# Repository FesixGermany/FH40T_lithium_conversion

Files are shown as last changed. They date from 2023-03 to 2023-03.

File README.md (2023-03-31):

# FH40T conversion to lithium battery  

The FH40T is a quite popular antique geiger counter in Germany from company Frieseke and Hoepfner.  
This particular unit is marked with the year of manufacture 1963.  
Originally it was powered by a long forgotten 6V battery or a NiCd rechargable battery.  
The previous owner built a small adapter to use two CR-V3 lithium batteries in series.  
I figured it could be powered by a modern standard 18650 rechargable lithium batery.  

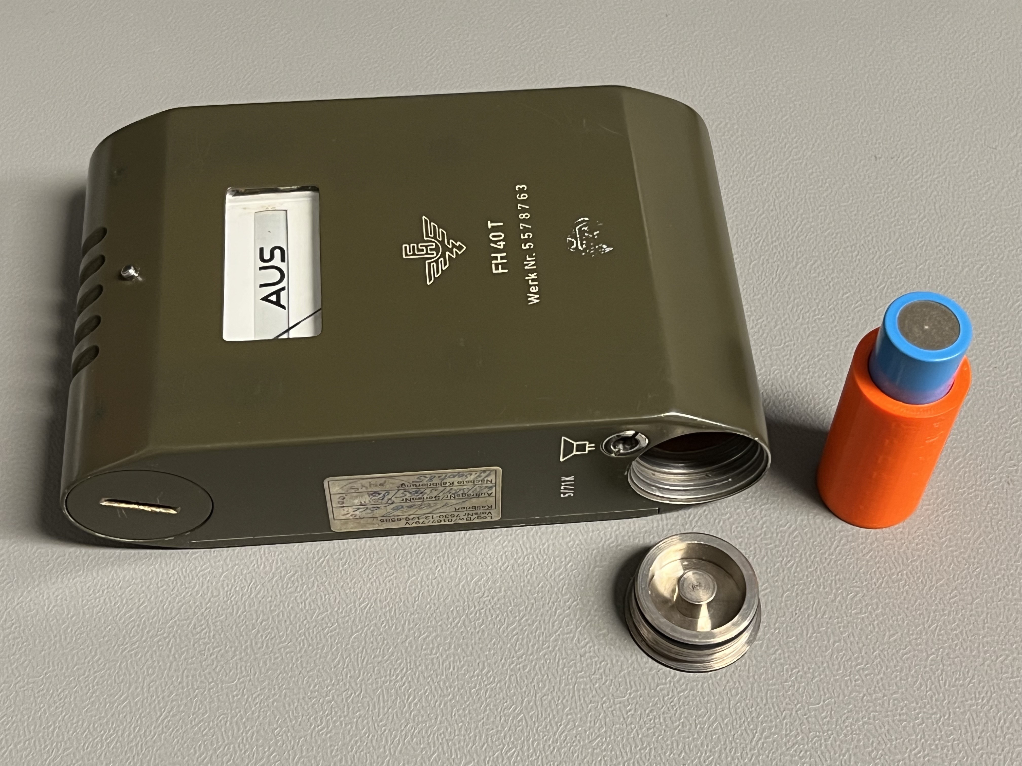
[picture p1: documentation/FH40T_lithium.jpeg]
FH40T with 18650 cell
  
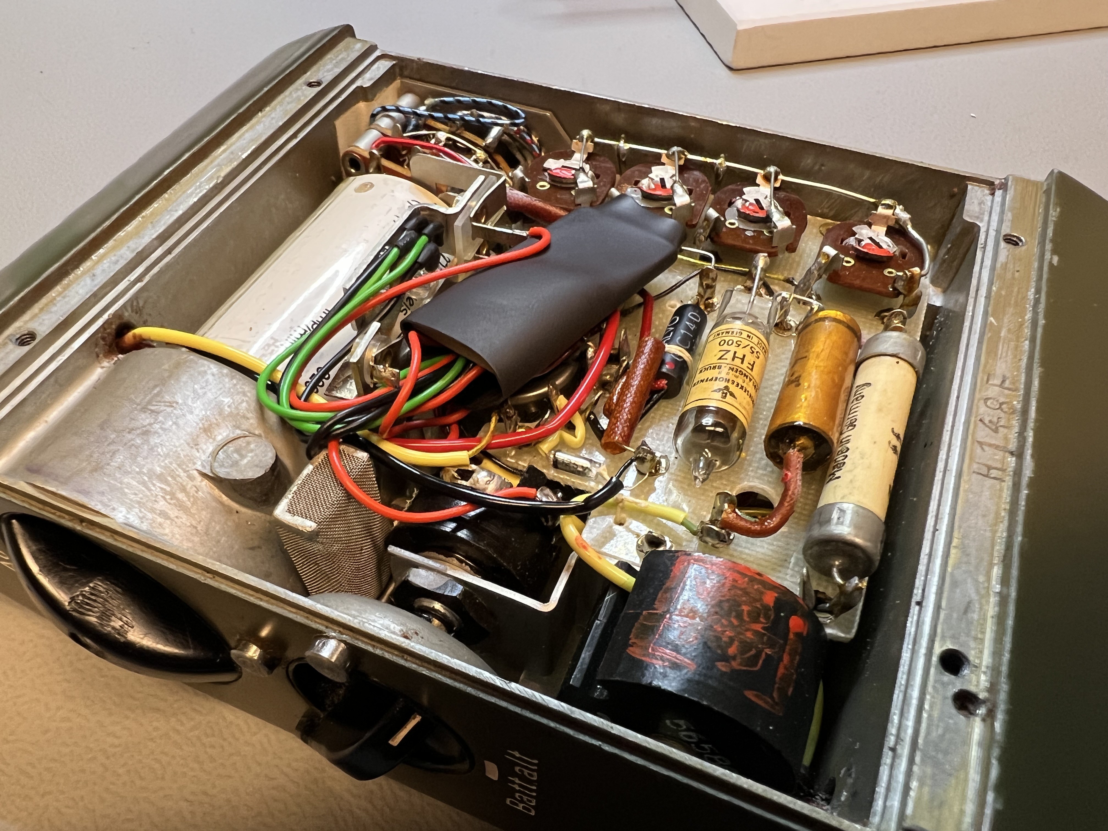
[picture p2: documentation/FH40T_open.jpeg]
FH40T with pcb
  

Needed was a adapter sleeve to fit the 18650 in the battery compartment, a protection circuit for the lithium cell and a step up converter to get a constant voltage.  
In addition I wanted to have some sort of carge indicator.  

## Protection circuit  

The protection circuit only needs to protect the cell against over discharging and is built around the standard DW01A protection IC.  
The only problem is, that normally it switches the low side of the connection. This can not be done with the FH40T because the whole case is used as ground.  
Therefore the P-channel MOSFET Q1 is used with help of Q2 to switch off the high side when the cell reaches 2.5V. R1 keeps the gate of Q1 discharged.  

## Step up converter  

The step up converter is built using the ME2108A IC I desoldered from a tiny step up module together with the schottky diode and inductor to provide a stable-ish voltage between 4.3V and 7V.  

## Charge indicator  

The charge indicator uses an ATtiny85 microcontroller that measures the voltage of the cell through a voltage divider consisting of R7 and R8, C4 was added in parallel to R8 for some low pass filtering.  
Although the controller is powered by the 5V from the step up it needs to use the internal 2.56V reference as the 5V is not stable enough.  
The cell voltage is displayed after the device is switched on by flashing a super bright red LED behind the scale and every time the voltage dropped by 100mV. Once the voltage dropped below 3V the LED flashes every 4s.  

## Lighting the scale  

Originally the scale was lit by a little incendescant bulb. Now a bright white LED is used switched on via Q3.  

## The PCB  

The PCB is a simple single sided board manufactures by isolation milling with my ISEL PCB router.  

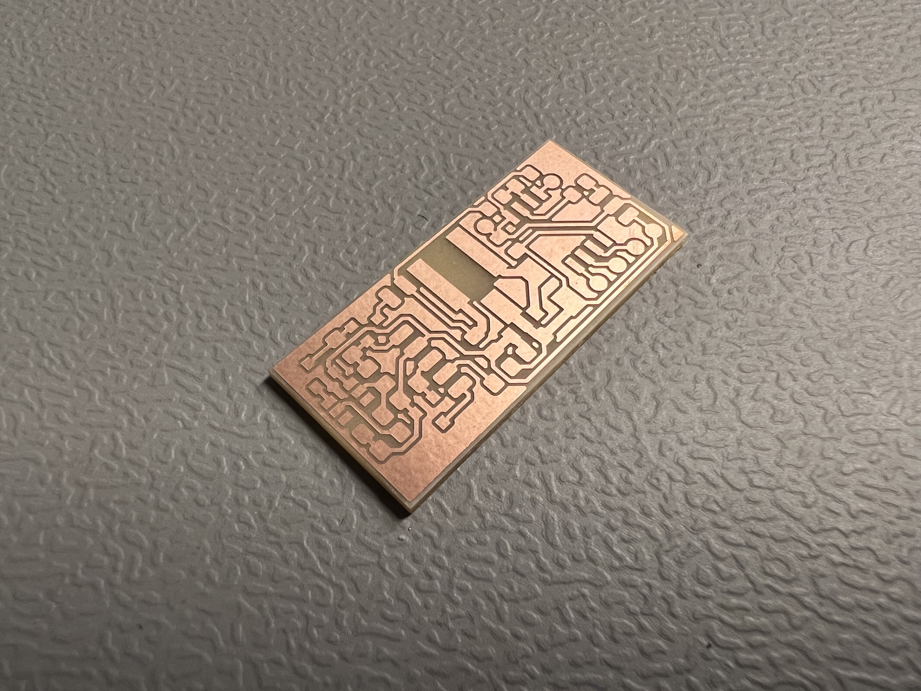
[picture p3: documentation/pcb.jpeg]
empty pcb
  
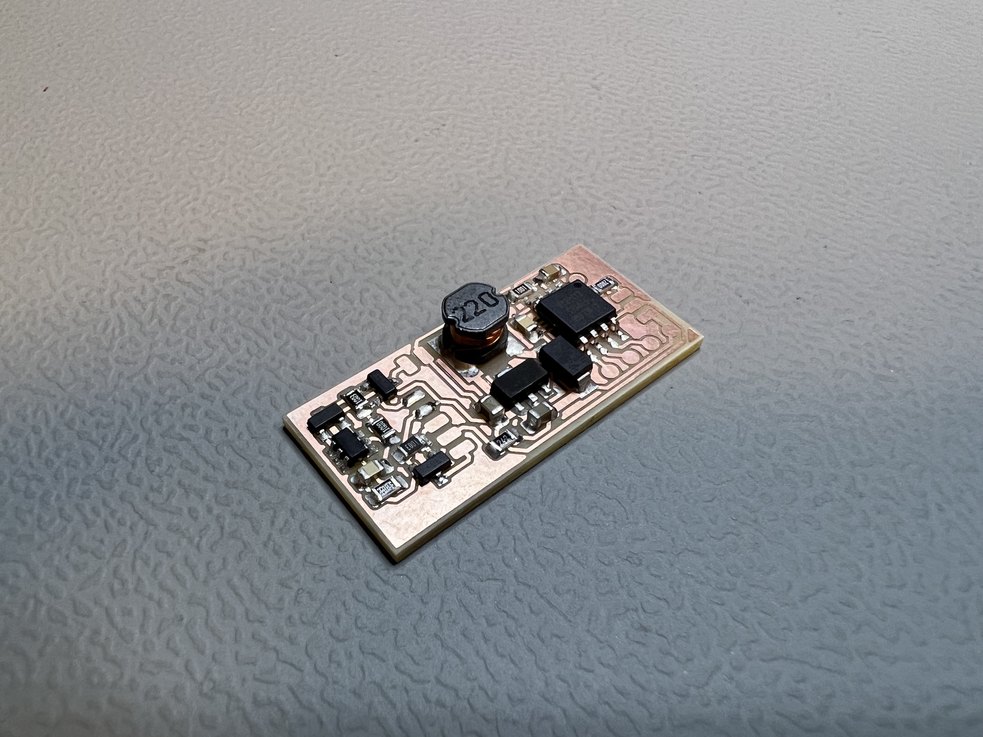
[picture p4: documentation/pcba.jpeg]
finished pcba
  

For interest here is the original schematic:  

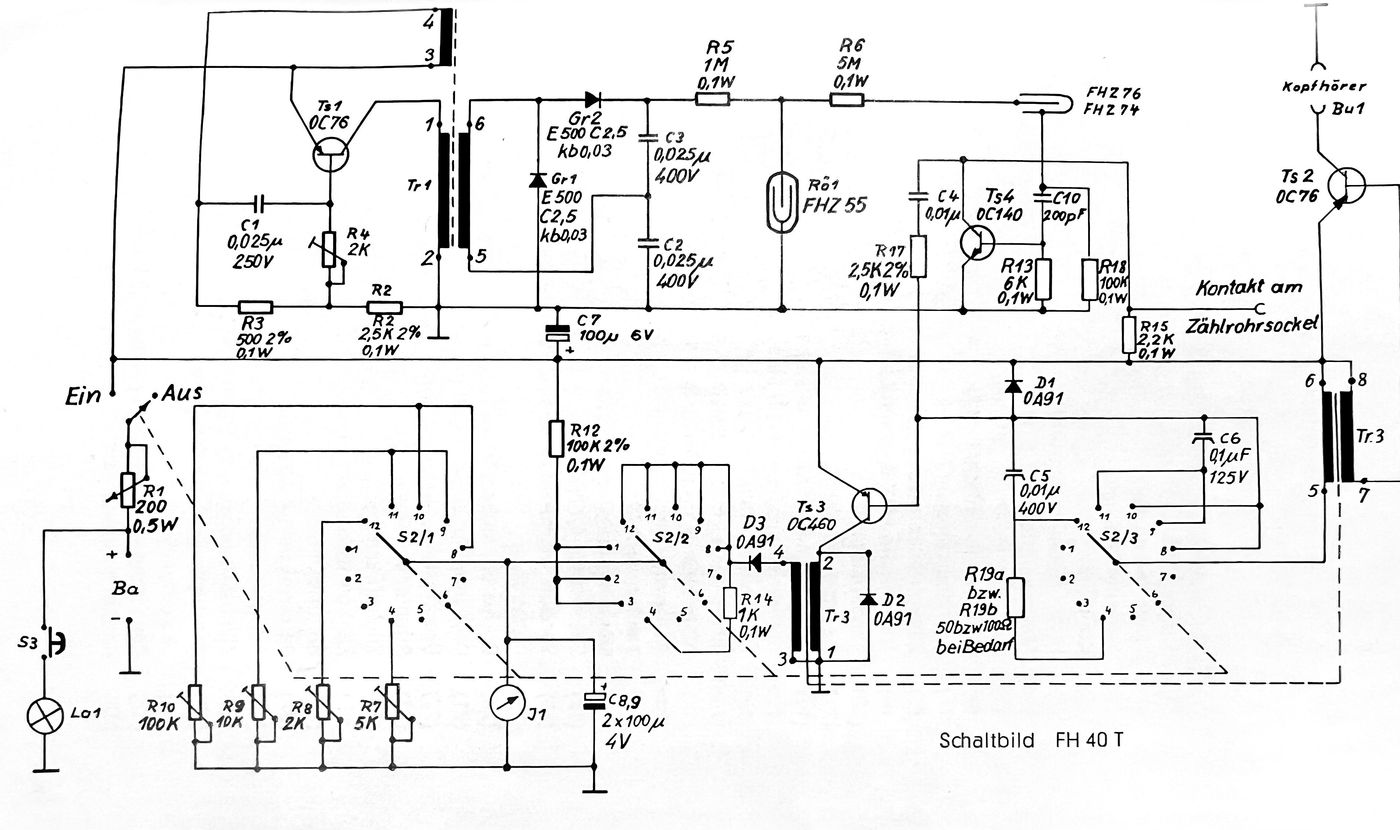
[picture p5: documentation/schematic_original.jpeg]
Original schematic


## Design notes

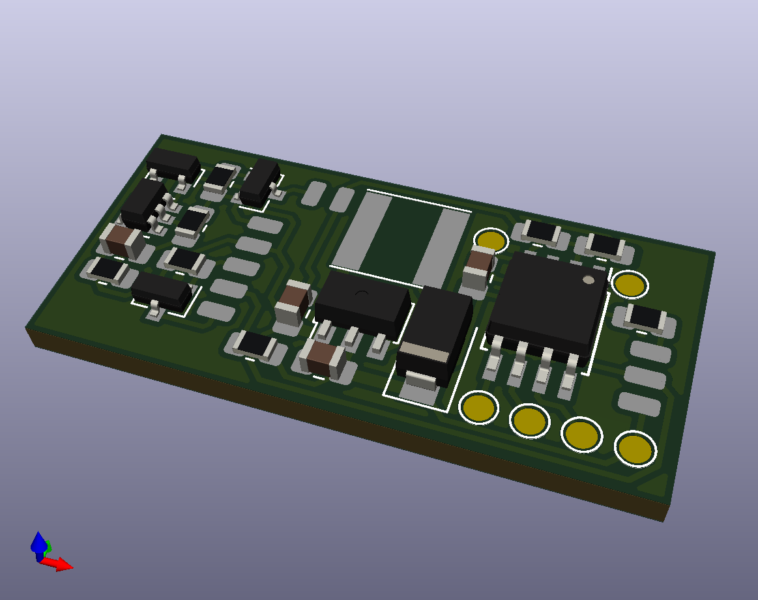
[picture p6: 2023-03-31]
pcb/FH40T_lithium_pcb.png

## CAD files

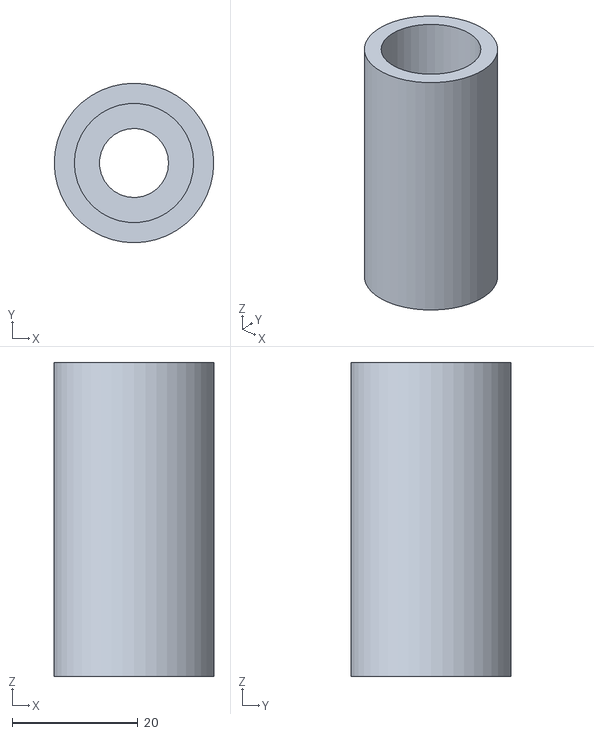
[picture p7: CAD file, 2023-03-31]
3D-prints/18650 sleeve-Body.stl
25.4 x 25.4 x 50.0

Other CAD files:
3D-prints/18650 sleeve.FCStd

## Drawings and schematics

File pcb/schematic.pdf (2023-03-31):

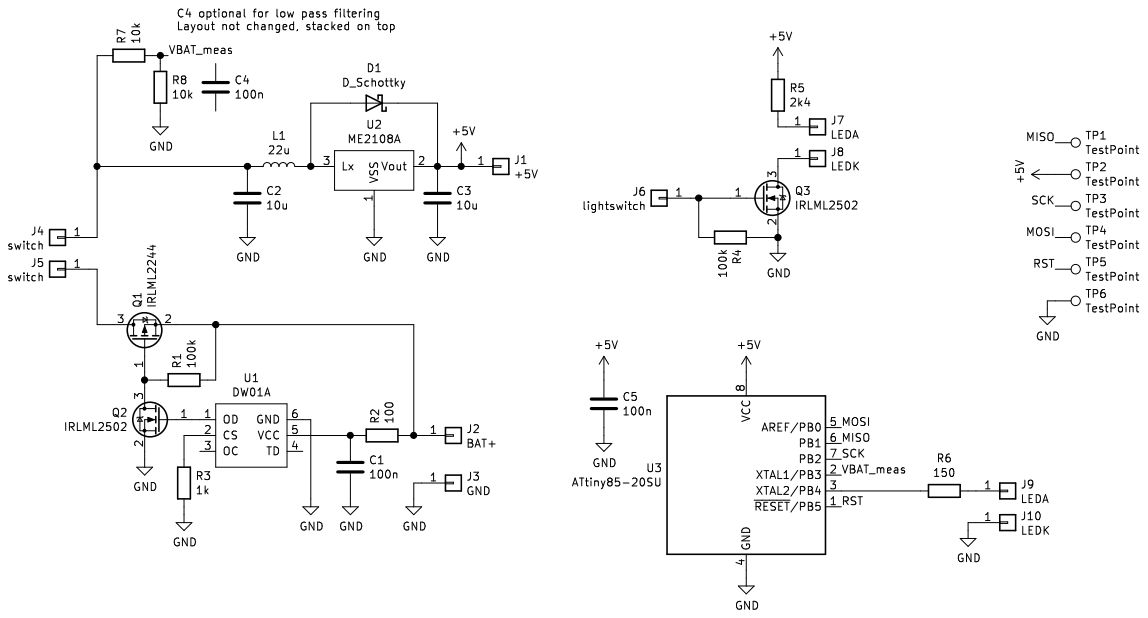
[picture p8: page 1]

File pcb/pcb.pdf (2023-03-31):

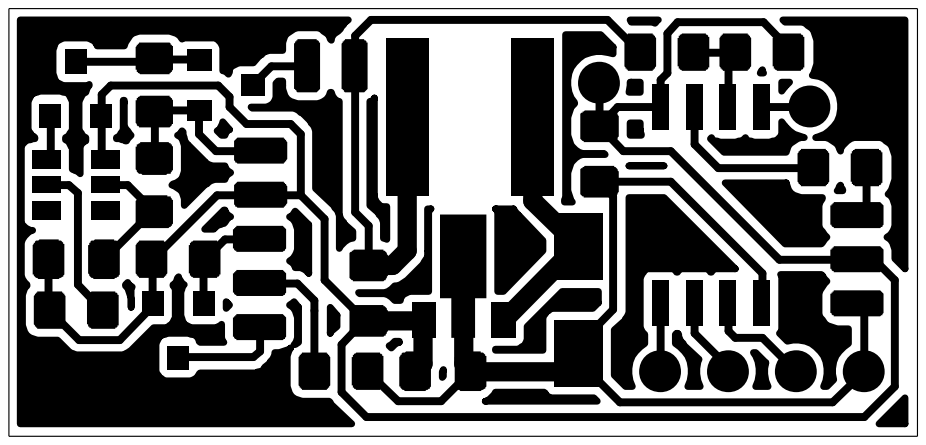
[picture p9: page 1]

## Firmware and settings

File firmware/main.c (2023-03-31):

/*
 * ATtiny85 used to measure voltage of a lithium battery
 * Flash the whole volts and the first decimal (100mV) upon start then measure every 4s and compare to last value blinked
 * If voltage dropped by 100mV then blink the voltage again
 * If voltage dropped below 3V then give one flash every time a measurement is done
 *
 * Created: 20/03/2023 19:27:53
 * Author : fesix
 *
 * LED output: PB4
 * Battery voltage input: PB3 (ADC 3)
 * 
 */ 

#define F_CPU 1000000UL

#include <avr/io.h>
#include <util/delay.h>
#include <avr/interrupt.h>

#define LED_PORT	PB4
#define ADCfactor	0.005

float voltage;
float voltage_last;
int volts_whole;
int volts_decimal;

// Initialize ADC
void ADC_init(void)
{
	uint16_t result;
	
	ADMUX |= (1 << REFS2) | (1 << REFS1);					// Internal 2.56V reference without ext. cap
	ADCSRA = (1 << ADPS2) | (1 << ADPS1) | (1 << ADPS0);	// 128 ADC clock prescaler
	ADCSRA |= (1 << ADEN);									// ADC enable
	
	//Dummy-Readout
	ADCSRA |= (1 << ADSC);									// ADC single conversion
	while (ADCSRA & (1 << ADSC)) {}							// Wait until conversion is finished
	
	result = ADCW;											// Read register of result and do nothing with it
}

// Read ADC value
uint16_t ADC_Read(uint8_t channel)
{
	ADMUX = (ADMUX & ~(0x0F)) | (channel & 0x0F);			// Select ADC channel without interfering with other bits in register
	ADCSRA |= (1 << ADSC);									// ADC single conversion
	while (ADCSRA & (1 << ADSC)) {}							// Wait until conversion is finished
	
	return ADCW;											// Return value
}

// Take multiple samples and average them
uint16_t ADC_Avg(uint8_t channel, uint8_t average)
{
	uint16_t adcsum = 0;
	
	for (int i = 0; i < average; i++)						// Read ADC a given number of times
	{
		adcsum += ADC_Read(channel);						// Add up all values
	}
	
	return adcsum / average;								// Divide sum by number of samples
}

//  Flash LED a given number of times
void flash_LED (uint8_t number)
{
	for (int i = 0; i < number; i++)
	{
		PORTB |= (1 << LED_PORT);							// LED on
		_delay_ms(100);
		PORTB &= ~(1 << LED_PORT);							// LED off
		_delay_ms(200);
	}
}


int main(void)
{
    DDRB |= (1 << LED_PORT);								// Output
	
	ADC_init();
	
	// Indicate charge after turning on
	voltage = ADC_Avg(3, 10) * ADCfactor;					// Read ADC and calculate battery voltage
	voltage_last = voltage;									// store last blinked value
	_delay_ms(1000);										// Wait a bit
	volts_whole = (int) voltage;							// Convert to whole volts
	flash_LED(volts_whole);									// Flash whole volts
	_delay_ms(1000);										// Wait a bit
	volts_decimal = (voltage * 10.0) - (volts_whole * 10.0);	// Calculate just the first decimal as int
	flash_LED((int) volts_decimal);							// Flash decimal

	// Timer configuration, as slow as possible (4s)
	TCCR1 |= (1 << CTC1) | (1 << CS13) | (1 << CS12) | (1 << CS11) | (1 << CS10);	// CTC mode, prescaler 16384
	OCR1C =	255;											// Compare value
	TIMSK |= (1 << OCIE1A);									// Interrupt enable
	
	sei();													// Enable global interrupts
	
	while(1)												// Do nothing, ISR does everything
	{}
}

ISR(TIMER1_COMPA_vect)
{
	voltage = ADC_Avg(3, 10) * ADCfactor;					// Read ADC and calculate battery voltage
	
	if (voltage < 3.0)										// If voltage dropped to less than 3V
	{
		flash_LED(1);										// Flash LED once every measurement
		_delay_ms(500);
	}
	
	if ((voltage_last-voltage) > 0.1)						// If voltage dropped by more than 100mV since last blinked value 
	{
			volts_whole = (int) voltage;							// Convert to whole volts
			flash_LED(volts_whole);									// Flash whole volts
			_delay_ms(1000);										// Wait a bit
			volts_decimal = (voltage * 10.0) - (volts_whole * 10.0);	// Calculate just the first decimal as int
			flash_LED((int) volts_decimal);							// Flash decimal
			
			voltage_last = voltage;									// Store last blinked value
	}
}
